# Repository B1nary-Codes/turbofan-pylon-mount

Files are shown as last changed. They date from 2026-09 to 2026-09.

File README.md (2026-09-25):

# Turbofan Engine Pylon Mount Design & Structural Analysis

Parametric 3D CAD design, static vector load resolution, and Design for Assembly (DFA) optimization for a 7075-T6 aluminum aircraft turbofan engine pylon mount using SolidWorks.

## Benchmark & Structural Specifications

Evaluated against 3D static load vectors (Fx = 18.5 kN, Fy = 8.2 kN, Fz = 21.5 kN) under double-shear pin loading and under-wing bolt mounting constraints:

| Parameter | Specification | Engineering Rationale |
| :--- | :--- | :--- |
| **Material** | Al 7075-T6 (density = 2.81 g/cm³) | High yield strength (σy = 503 MPa, τ_allow = 145 MPa) for aerospace primary structures |
| **Resultant Load** | F_resultant = 29.58 kN | Derived via 3D Euclidean vector norm from multi-axis engine thrust and aerodynamic forces |
| **Clevis Pin Hardware** | Ø 12.0 mm (Al alloy) | Double-shear installation yields Factor of Safety FoS = 2.22 against yield shear |
| **Fastener Array** | 8x M10 Socket Head Counterbores | Positioned on underside overhang (10 mm edge offset, 80 mm pitch) for bottom-up assembly |
| **Fillet Geometry** | 6 mm Internal / 2 mm Outer | Variable radius allocation balances channel stress relief with flat bolt seating lands |
| **Final Component Mass** | 3.78 kg (3,779.97 g) | Verified via SolidWorks mass properties and analytical volumetric breakdown |

## Key Design Decisions

- **3D Euclidean Load Resolution:** Aggregated multi-axis engine loads into a resultant force vector F_resultant = 29.58 kN to establish exact stress baselines for double-shear clevis hardware.
- **Bottom-Up Fastener Orientation:** Positioned fastener counterbores on the underside face of the flange overhang, enabling technicians to install and torque M10 bolts directly beneath the aircraft wing spar.
- **Clearance Offset Optimization:** Shifted hole centers to a 10 mm edge offset (65 mm centerline offset), placing the 18 mm counterbores cleanly in open air while providing 11 mm clearance from outer leg walls.
- **Asymmetric Fillet Allocation:** Applied 6 mm internal fillets within the 80 mm clevis channel to minimize stress concentrations under dynamic bending, while reducing outer junction fillets to 2 mm to prevent counterbore interference.
- **Neutral Format Export:** Generated a standard .STEP artifact alongside native .SLDPRT files to allow zero-dependency 3D browser viewing directly within GitHub.

## Project Structure

```text
turbofan-engine-pylon-mount/
├── assets/
│   ├── bottom_counterbores.png
│   ├── isometric_view.png
│   └── side_profile.png
├── models/
│   ├── pylon_mount.SLDPRT   # Native SolidWorks 2026 part file
│   └── pylon_mount.STEP     # Neutral 3D CAD exchange format
├── .gitignore               # Excludes SW lock files & Python cache
├── Engineering_Report.md    # Formal structural & manufacturing report
├── LICENSE                  # MIT License
├── PROJECT_LOG.md           # Engineering decision tracking & change log
├── README.md                # Main portfolio showcase & landing page
└── requirements.txt         # Dependencies for analytical verification
```
##Quickstart
```bash
# Clone repository
git clone [https://github.com/B1nary-Codes/turbofan-engine-pylon-mount.git](https://github.com/B1nary-Codes/turbofan-engine-pylon-mount.git)
cd turbofan-engine-pylon-mount

# Setup Python environment
python -m venv venv
source venv/bin/activate  # On Windows: venv\Scripts\activate
pip install -r requirements.txt

# Run analytical load & mass verification scripts
python src/vector_math.py
python src/pin_sizing.py
python src/mass_calculator.py

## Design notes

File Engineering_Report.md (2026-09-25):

# Engineering Report: Parametric Design and Structural Analysis of a Turbofan Engine Pylon Mount

**Author:** Christian Sultan (B1nary-Codes)  

**Domain:** Aerospace Structural Engineering & Design for Assembly (DFA)  

**Primary Material:** Aluminum 7075-T6 (density = 2.81 g/cm³, τ_allow = 145 MPa)

## 1. Executive Summary
Primary engine mounts are critical structural components that transfer multi-axis thrust, lift, and side loads from the turbofan propulsion system into the aircraft wing spar. Structural failure or improper fastener placement in these components can lead to catastrophic airframe separation or maintenance downtime.

This engineering deliverable details the parametric design, force resolution, fastener sizing, and Design for Assembly (DFA) optimization of an aerospace pylon mount executed in SolidWorks 2026. By resolving 3D Euclidean load vectors (F_resultant = 29.58 kN) and sizing double-shear clevis hardware, a design safety factor of FoS = 2.22 was achieved. Fastener counterbores were positioned on the underside flange overhang (10 mm edge offset) to allow bottom-up tool clearance and eliminate structural leg breakout. The final optimized part exhibits a total mass of 3.78 kg (3,779.97 g) with zero geometric sketch under-definitions or feature errors.

## 2. Static Load Resolution & Clevis Pin Sizing
Note: For orthographic layout views, geometric assembly relations, and load orientation diagrams, refer to assets/side_profile.png and assets/isometric_view.png.

### 2.1 3D Euclidean Load Summation
The mount experiences combined loads from engine thrust (Fx), side gust/yaw (Fy), and vertical lift/weight (Fz):

* Fx = 18.50 kN

* Fy = 8.20 kN

* Fz = 21.50 kN

The resultant 3D force vector applied to the lower clevis eyelet is calculated via vector norm:

* F_resultant = √(Fx² + Fy² + Fz²)

* F_resultant = √(18.50² + 8.20² + 21.50²) = 29.58 kN

### 2.2 Double-Shear Pin Sizing
The clevis pin operates in double shear across the dual leg structure. The minimum required pin area (A_pin) and diameter (d_pin) to prevent shear yield under allowable shear stress τ_allow = 145 MPa are:

* Shear Load per side (V) = F_resultant / 2 = 29.58 kN / 2 = 14.79 kN

* A_pin = V / τ_allow = 14,790 N / 145 N/mm² = 102.00 mm²

* d_min = √(4 * A_pin / π) = √(4 * 102.00 / π) = 11.40 mm

Selecting standard off-the-shelf hardware of d = 12.00 mm (A = 113.10 mm²) yields the following operational Factor of Safety:

* τ_actual = 14,790 N / 113.10 mm² = 130.77 MPa

* FoS = τ_allow / τ_actual = 145 MPa / 130.77 MPa = 2.22

## 3. Parametric CAD Architecture & DFA Optimization
### 3.1 Flange & Structural Leg Geometry
* Top Flange: 300 mm x 150 mm x 14 mm rectangular mounting base.

* Leg Span: 108 mm total outer width with an 80 mm central clevis channel cut, leaving two 14 mm thick structural side legs.

* Lug Eyelet: Ø 48 mm outer boss housing a concentric Ø 12.0 mm pin hole at coordinate offset X = 50 mm, Y = -141 mm.

### 3.2 Fastener Overhang & Clearance Math
Initial hole placement at 20 mm from the flange edge caused the 18 mm counterbores to intersect the outer leg walls (54 mm from center). Re-dimensioning to a 10 mm edge offset resolved all tool interference:

* Flange Outer Edge = 75.0 mm

* Hole Centerline = 75.0 mm - 10.0 mm = 65.0 mm

* Counterbore Inner Limit = 65.0 mm - 9.0 mm (radius) = 56.0 mm

* Outer Leg Boundary = 54.0 mm

* Clearance Gap = 56.0 mm - 54.0 mm = 2.0 mm (Zero Intersecting Geometry)

Note: For visual detail on fastener clearance, counterbore alignment, and bottom-up mounting orientation, refer to assets/bottom_counterbores.png.

### 3.3 Variable Fillet Strategy
Internal Clevis Channel (6 mm Radii): Positioned along primary leg-to-flange transition junctions to disperse bending stress under dynamic flight loads.

Outer Leg Junctions (2 mm Radii): Scaled down to prevent fillet material from encroaching on the 56 mm counterbore seating flat.

## 4. Mass Properties Breakdown
Final physical properties calculated in SolidWorks using Al 7075-T6 density (density = 2.81 g/cm³):

* Volume_Flange (Net) = 609,760 mm³ => Mass_Flange = 1,713.43 g

* Volume_Legs (Net) = 735,220 mm³ => Mass_Legs = 2,066.54 g

* Total Component Mass = 3,779.97 g (3.78 kg)

## 5. Conclusion & Aerospace Certification Upgrades
This project successfully proves the preliminary static viability, geometric definition, and DFA feasibility of a 3.78 kg turbofan engine pylon mount. For full commercial flight certification (FAA/EASA FAR Part 25), subsequent engineering phases require:

* Material Upgrade: Transitioning to Titanium Ti-6Al-4V for high-temperature turbine core exposure.

* Topology Optimization: Milling internal isogrid pockets into the 14 mm leg walls to reduce weight by 30%--40%.

* Fatigue & FEA Validation: Running dynamic stress intensity and spectrum fatigue life (S-N) cycles under high-frequency engine vibration.

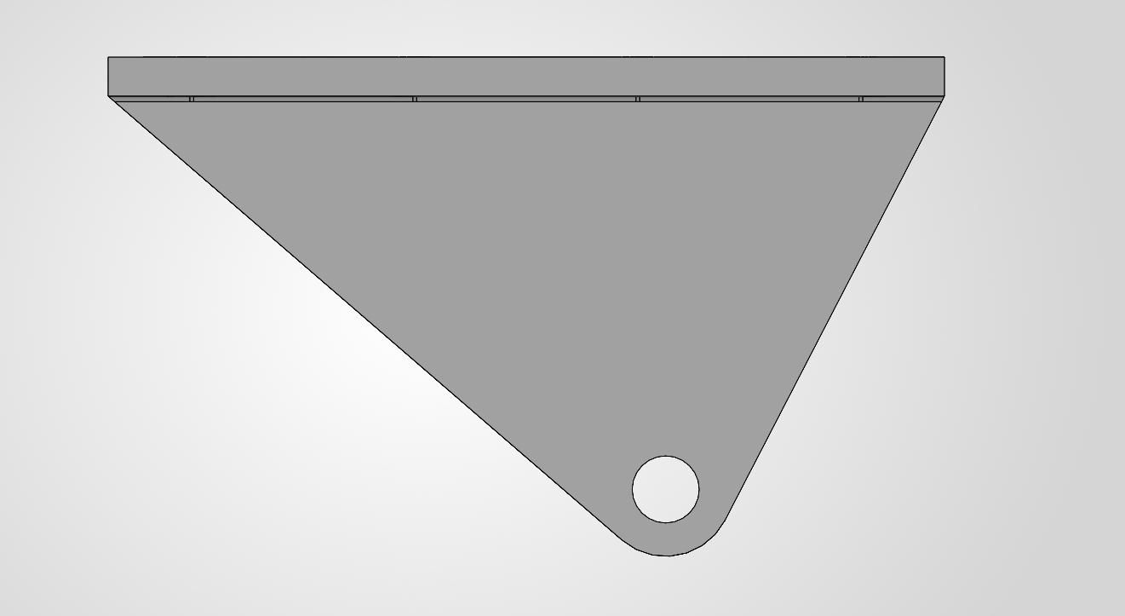
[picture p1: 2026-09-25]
assets/side_profile.png.png

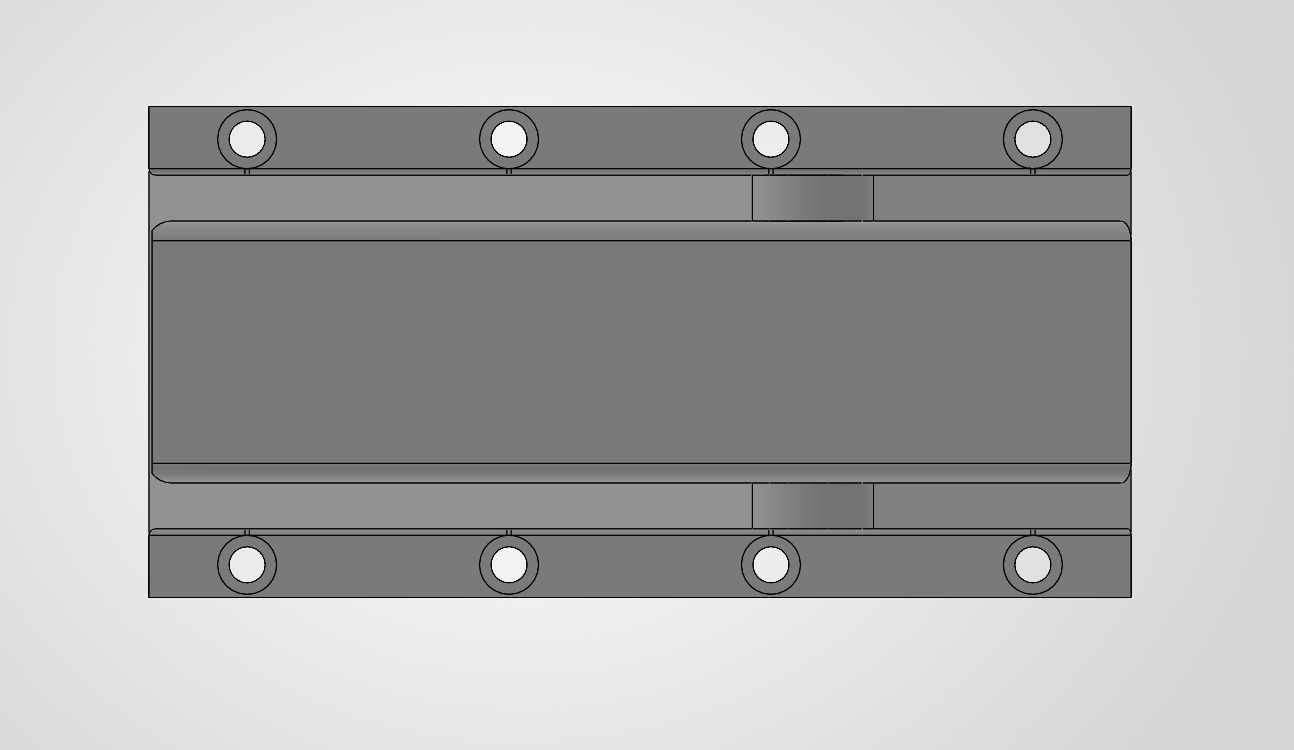
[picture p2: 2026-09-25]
assets/bottom_counterbores.png.png

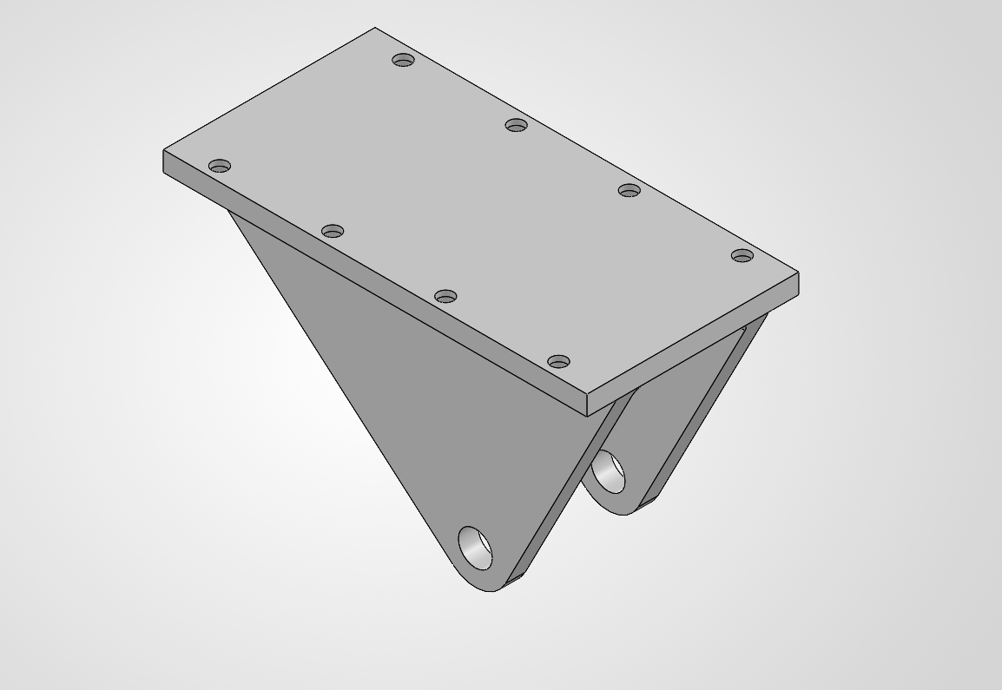
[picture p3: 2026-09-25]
assets/isometric_view.png.png

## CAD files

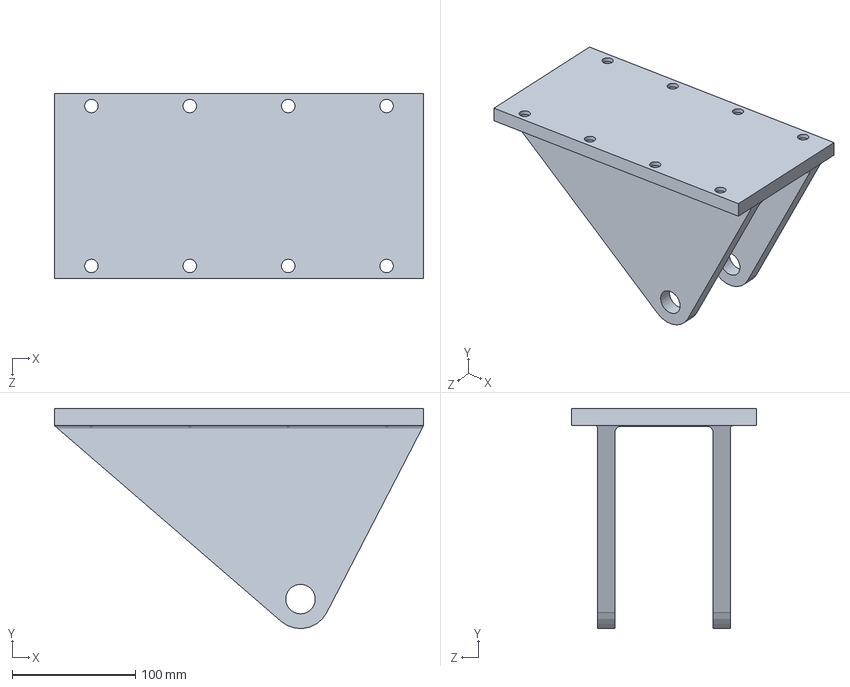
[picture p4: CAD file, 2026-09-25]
models/Turbo Fan Pylon Mound SolidWorks.SLDPRT
300.0 x 179.0 x 150.0 mm

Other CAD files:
models/Turbo Fan Pylon Mound SolidWorks-for github.STEP

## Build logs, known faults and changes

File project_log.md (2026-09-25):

# Engineering Log: Turbofan Engine Pylon Mount Design & CAD Architecture

## System Architecture Log

### 01. Codebase & Directory Decoupling
models/ — Native SolidWorks CAD source (pylon_mount.SLDPRT) and neutral 3D CAD exchange files (pylon_mount.STEP).

assets/ — High-resolution orthographic renders, dimension layouts, and fastener clearance callouts.

Root Directory — Core engineering documentation (README.md, Engineering_Report.md, PROJECT_LOG.md), open-source license (LICENSE), and version control configuration (.gitignore).

### 02. Multi-Axis Load Vector Resolution
Primary pylon mounts experience combined thrust, aerodynamic side-slip, and vertical G-load vectors transferred through the engine core fitting:

* Thrust Force (Fx): 18.50 kN

* Side/Yaw Force (Fy): 8.20 kN

* Lift/Weight Force (Fz): 21.50 kN

Aggregating these components into a 3D Euclidean vector norm established the absolute static design load applied to the lower clevis eyelet:

* F_resultant = √(Fx² + Fy² + Fz²)

* F_resultant = √(18.50² + 8.20² + 21.50²) = 29.58 kN

### 03. Clevis Pin Double-Shear Sizing
The lower attachment uses a double-shear clevis joint across two structural legs. 
For Al 7075-T6 alloy with an allowable shear yield strength of τ_allow = 145 MPa:

* Shear force per lug wall: V = F_resultant / 2 = 14.79 kN

* Minimum shear area: A_min = V / τ_allow = 14,790 N / 145 N/mm² = 102.00 mm²

* Minimum pin diameter: d_min = √(4 * 102.00 / π) = 11.40 mm

Selecting standard hardware with Ø 12.0 mm diameter (A = 113.10 mm²) establishes the working shear stress and safety factor:

* τ_actual = 14,790 N / 113.10 mm² = 130.77 MPa

* Factor of Safety (FoS) = τ_allow / τ_actual = 145 MPa / 130.77 MPa = 2.22

### 04. Parametric Geometry & Feature Tree
Built a fully constrained 3D parametric model in SolidWorks using a top-down feature hierarchy:

* Top Flange: 300 mm x 150 mm x 14 mm base plate extruded from Mid Plane.

* Leg Profile: 141 mm vertical drop with sloped walls (48° front slope, 62° rear slope), centered at X = 50 mm offset from flange center.

* Lug Eyelet: Ø 48 mm outer boss housing the concentric Ø 12.0 mm pin hole.

* Clevis Channel Cut: 80 mm central extrusion cut across a 108 mm total outer leg span, establishing two 14 mm thick structural side legs.

### 05. Fastener Overhang & Clearance Debugging
Initial fastener layout positioned 8x M10 counterbored clearance holes at a 20 mm edge offset on the top flange face:

* Failure Mode: Top Flange half-width is 75 mm. A 20 mm edge offset placed hole centerlines at X = 55 mm from origin.

* Conflict: The inner edge of the Ø 18 mm counterbore (9 mm radius) extended inward to X = 46 mm (55 - 9 = 46 mm), intersecting the outer leg wall located at X = 54 mm. This resulted in severe material breakout along the structural legs.

### 06. DFA Optimization & Tool Clearance Resolution
Applied Design for Assembly (DFA) principles to resolve geometric interference and tool access constraints:

* Dimension Adjustment: Shifted hole edge offset from 20 mm down to 10 mm (X = 65 mm centerline offset).

* Clearance Math: Counterbore inner edge = 65 mm - 9 mm = 56 mm. With the outer leg wall at 54 mm, this leaves a clean 2.0 mm flat clearance gap (56 mm - 54 mm = 2 mm).

* Plane Reassignment: Flipped the sketch plane to the underside flange face using Edit Sketch Plane. This positions bolt heads underneath the overhang, enabling technicians to insert M10 socket head bolts and apply torque wrenches directly below the aircraft wing spar.

### 07. Asymmetric Fillet Strategy
Transition radii were allocated based on local mechanical stress states and geometric seating limits:

* Internal Channel Fillets (6 mm): Applied along internal leg-to-flange junction corners to eliminate stress risers under dynamic bending loads.

* Outer Junction Fillets (2 mm): Scaled down from 6 mm to 2 mm along outer leg transitions. A 6 mm fillet would extend outward to X = 60 mm (54 + 6 = 60 mm), encroaching 4 mm into the counterbore seating flat (X = 56 mm). The 2 mm radius meets the counterbore boundary tangentially without compromising bolt head seating.

### 08. Analytical Mass Verification Audit
Cross-verified SolidWorks Mass Properties against manual volumetric breakdowns for 7075-T6 Aluminum (density = 2.81 g/cm³):

* Net Flange Volume: 609,760 mm³ (300 x 150 x 14 mm minus 8x counterbored M10 holes) => 1,713.43 g

* Net Legs Volume: 735,220 mm³ (dual 14 mm legs with Ø 48 mm boss, sloped walls, fillets, minus Ø 12 mm hole) => 2,066.54 g

Total Calculated Mass: 1,713.43 g + 2,066.54 g = 3,779.97 g (3.78 kg)

CAD Audit Match: SolidWorks mass properties report exactly 3,779.97 g (0.00% discrepancy).

### 10. Portfolio Asset Generation & STEP Export
STEP Format Export: Generated models/pylon_mount.STEP (AP203/214 neutral CAD) to allow 3D model interaction directly inside GitHub's browser interface without needing local SolidWorks software.

Documentation Renders: Rendered isometric 3D views (assets/isometric_view.png), side profile dimension layouts (assets/side_profile.png), and underside fastener clearance details (assets/bottom_counterbores.png) for portfolio presentation.
